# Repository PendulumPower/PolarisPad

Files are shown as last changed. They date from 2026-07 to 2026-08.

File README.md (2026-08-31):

# PolarisPad
A Macropad designed for space combat in games such as Star Citizen.<br>
Finished Device
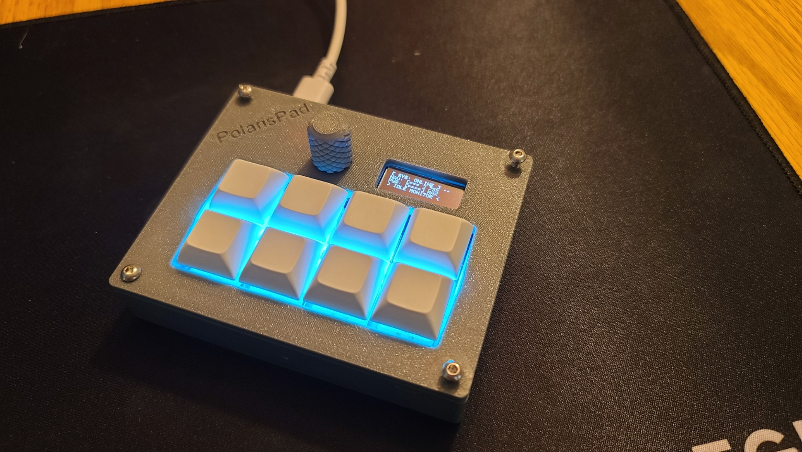
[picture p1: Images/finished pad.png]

Case:

Full Design:

PCB:

Schematic:

How to program:<br>
1. Connect the device to a computer using a usb-c data cable while pressing the boot button.<br>
2. Download the most recent .uf2 file from the releases.<br>
3. Drag and drop the .uf2 file into the folder for the device. It should close and reboot<br>
4. Done!<br>

BOM: <br>
-8 MX-Style switches <br>
-1 unsoldered Seeed XIAO RP2040 <br>
-8 through-hole 1N4148 Diodes <br>
-4 SK6812 MINI-E LEDs <br>
-1 EC11 Rotary encoders <br>
-1 0.91 inch OLED display

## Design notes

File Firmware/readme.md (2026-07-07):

# polarispad

polarispad

*A short description of the keyboard/project*

* Keyboard Maintainer: [Par Gunderson](https://github.com/PendulumPower)
* Hardware Supported: *The PCBs, controllers supported*
* Hardware Availability: *Links to where you can find this hardware*

Make example for this keyboard (after setting up your build environment):

    make polarispad:default

Flashing example for this keyboard:

    make polarispad:default:flash

See the [build environment setup](https://docs.qmk.fm/#/getting_started_build_tools) and the [make instructions](https://docs.qmk.fm/#/getting_started_make_guide) for more information. Brand new to QMK? Start with our [Complete Newbs Guide](https://docs.qmk.fm/#/newbs).

## Bootloader

Enter the bootloader in 3 ways:

* **Bootmagic reset**: Hold down the key at (0,0) in the matrix (usually the top left key or Escape) and plug in the keyboard
* **Physical reset button**: Briefly press the button on the back of the PCB - some may have pads you must short instead
* **Keycode in layout**: Press the key mapped to `QK_BOOT` if it is available

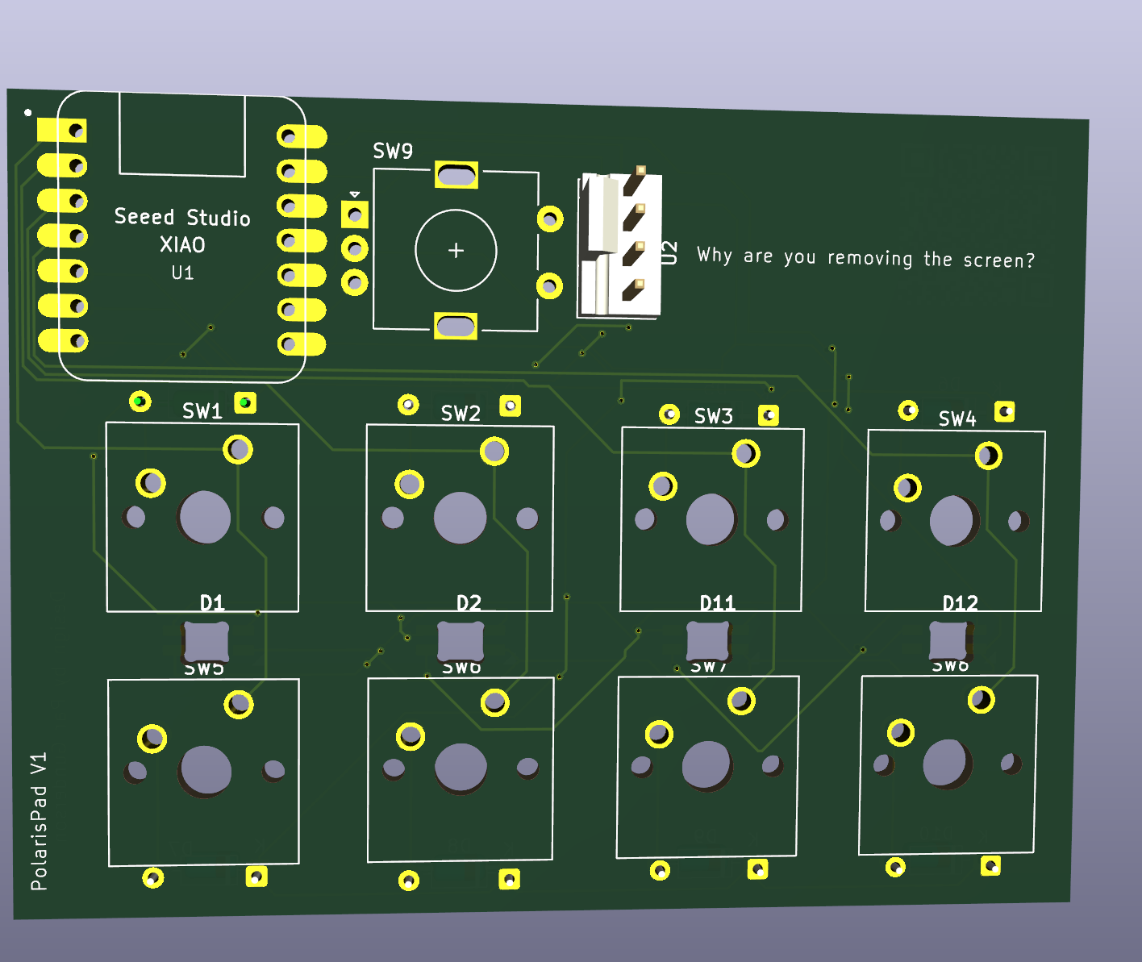
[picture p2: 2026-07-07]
Images/Screenshot 2026-07-06 182143.png

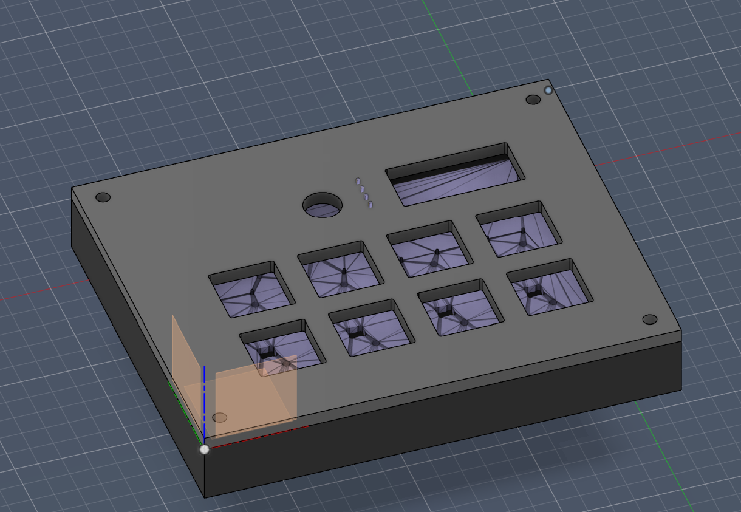
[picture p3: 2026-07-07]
Images/Screenshot 2026-07-06 095448.png

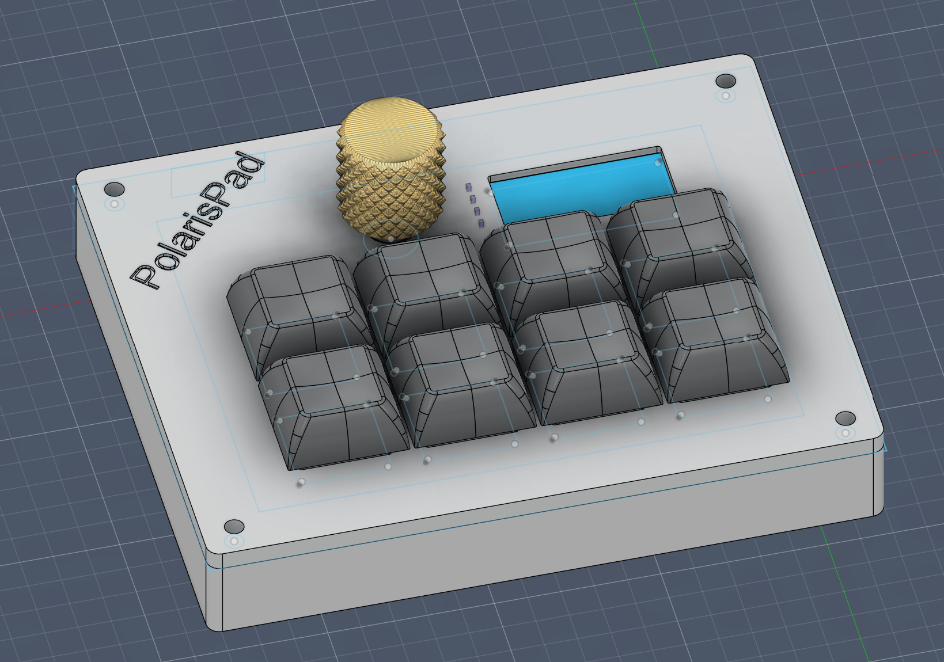
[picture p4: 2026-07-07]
Images/Screenshot 2026-07-06 175424.png

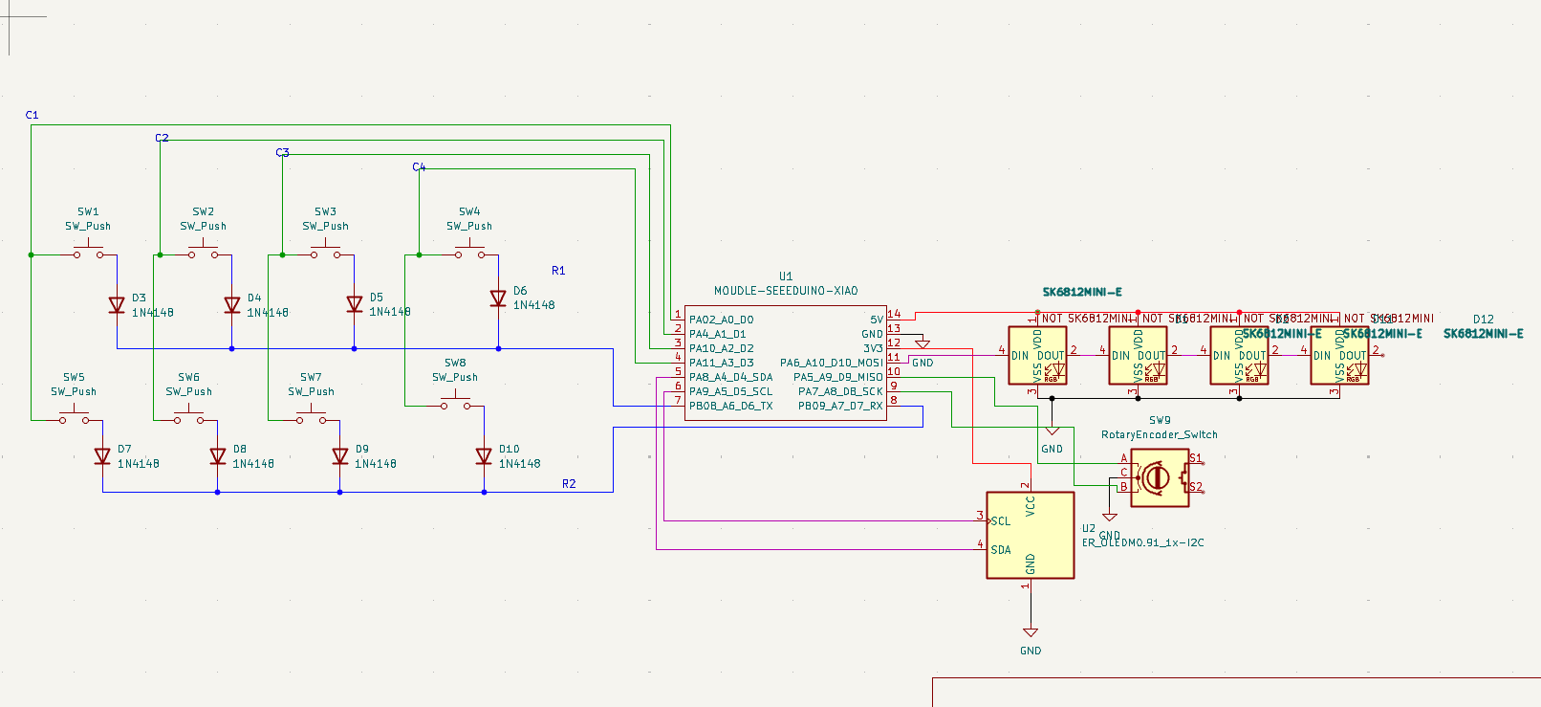
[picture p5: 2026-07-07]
Images/Screenshot 2026-07-07 163543.png

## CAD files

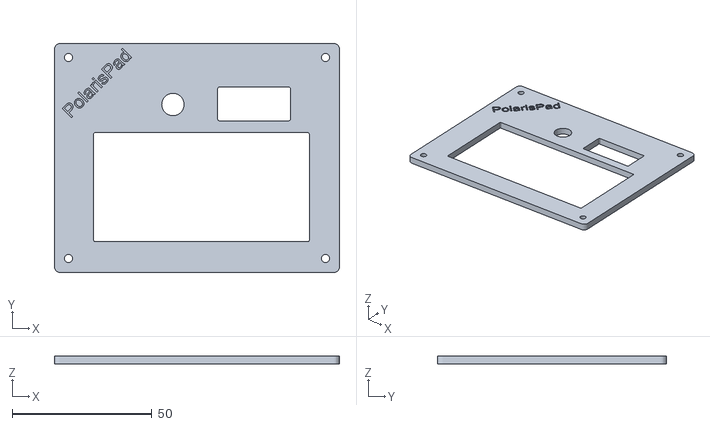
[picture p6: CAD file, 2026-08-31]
Production/PolarisPad_Case Top Plate.stl
101.8 x 81.8 x 3.00

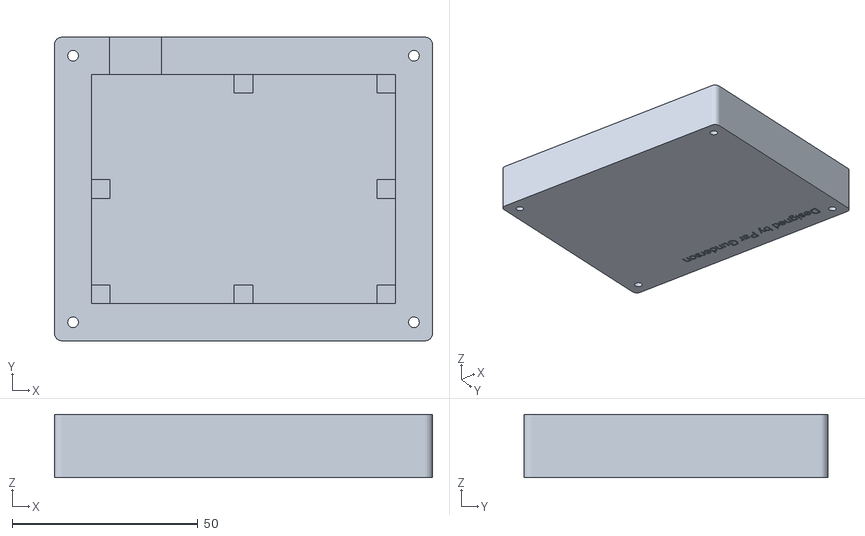
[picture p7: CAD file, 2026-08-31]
Production/PolarisPad_Case Bottom.stl
101.8 x 81.8 x 17.0

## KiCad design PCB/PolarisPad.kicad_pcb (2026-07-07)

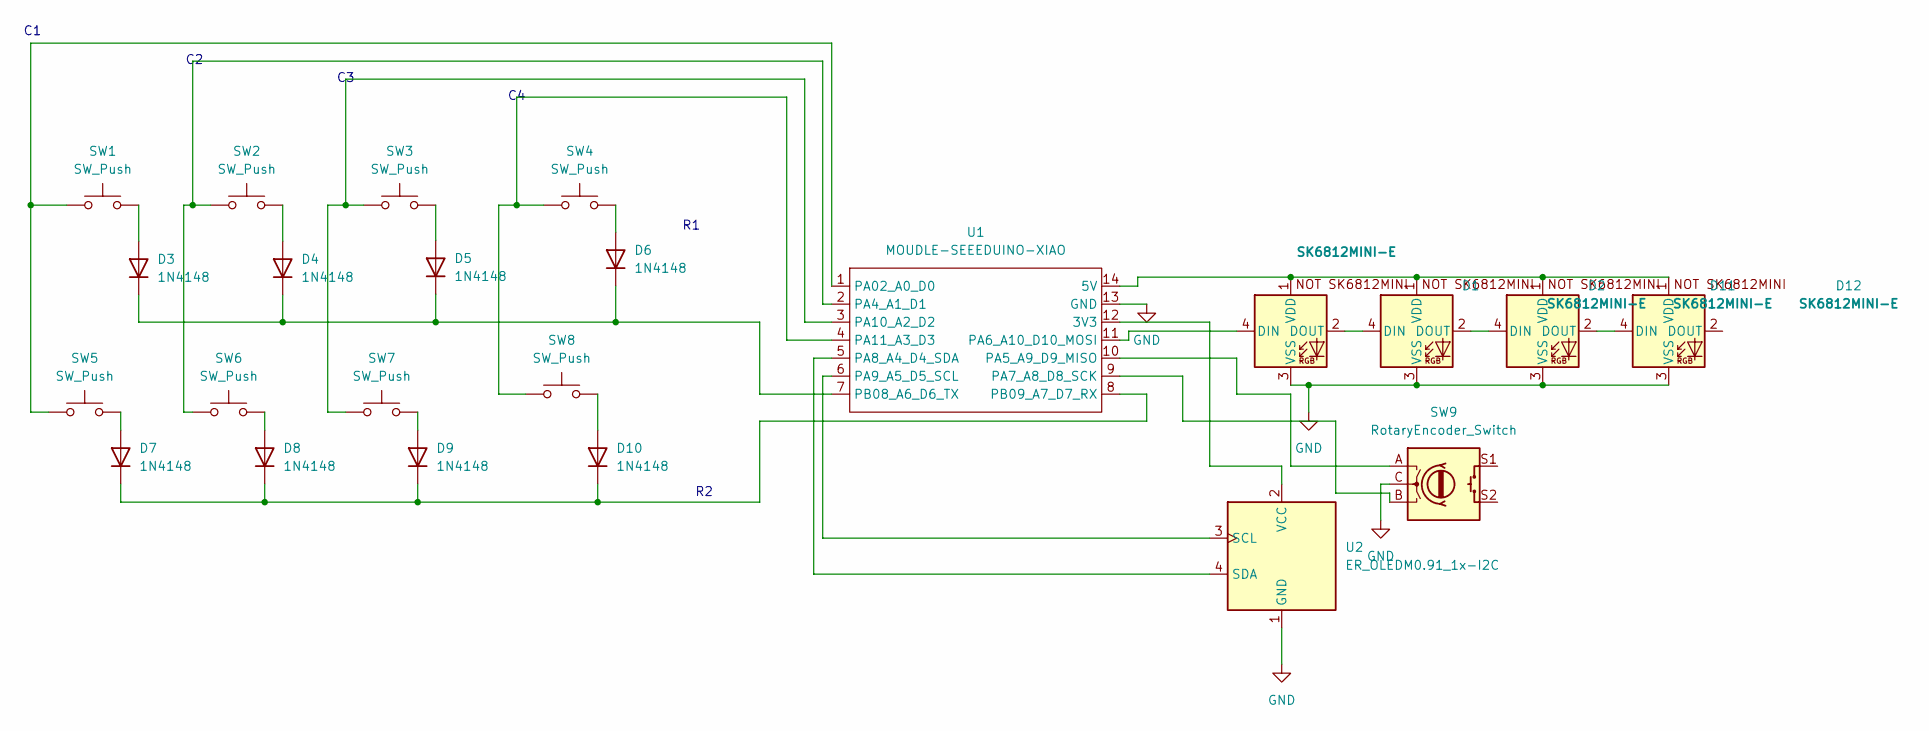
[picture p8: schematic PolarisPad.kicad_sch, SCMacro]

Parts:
D1, D2, D11, D12: SK6812MINI-E; SK6812MINI-E_fixed
D3, D4, D5, D6, D7, D8, D9, D10: 1N4148; D_DO-35_SOD27_P7.62mm_Horizontal
SW1, SW2, SW3, SW4, SW5, SW6, SW7, SW8: SW_Push; SW_Cherry_MX_1.00u_PCB
SW9: RotaryEncoder_Switch; RotaryEncoder_Alps_EC11E-Switch_Vertical_H20mm
U1: MOUDLE-SEEEDUINO-XIAO; XIAO-Generic-Hybrid-14P-2.54-21X17.8MM
U2: ER_OLEDM0.91_1x-I2C; FanPinHeader_1x04_P2.54mm_Vertical

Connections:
GND: D1.3 (VSS), D2.3 (VSS), D11.3 (VSS), D12.3 (VSS), SW9.C, U1.13 (GND), U2.1 (GND)
unnamed: D1.4 (DIN), U1.11 (PA6_A10_D10_MOSI)
unnamed: D1.2 (DOUT), D2.4 (DIN)
unnamed: D1.1 (VDD), D2.1 (VDD), D11.1 (VDD), D12.1 (VDD), U1.14 (5V)
unnamed: D3.2 (A), SW1.2
unnamed: D3.1 (K), D4.1 (K), D5.1 (K), D6.1 (K), U1.7 (PB08_A6_D6_TX)
unnamed: D4.2 (A), SW2.2
unnamed: D5.2 (A), SW3.2
unnamed: D6.2 (A), SW4.2
unnamed: D7.2 (A), SW5.2
unnamed: D8.2 (A), SW6.2
unnamed: D9.2 (A), SW7.2
unnamed: D10.2 (A), SW8.2
unnamed: D7.1 (K), D8.1 (K), D9.1 (K), D10.1 (K), U1.8 (PB09_A7_D7_RX)
unnamed: D2.2 (DOUT), D11.4 (DIN)
unnamed: D11.2 (DOUT), D12.4 (DIN)
unnamed: U1.12 (3V3), U2.2 (VCC)
unnamed: SW1.1, SW5.1, U1.1 (PA02_A0_D0)
unnamed: SW2.1, SW6.1, U1.2 (PA4_A1_D1)
unnamed: SW9.A, U1.10 (PA5_A9_D9_MISO)
unnamed: SW9.B, U1.9 (PA7_A8_D8_SCK)
unnamed: U1.5 (PA8_A4_D4_SDA), U2.4 (SDA)
unnamed: U1.6 (PA9_A5_D5_SCL), U2.3 (SCL)
unnamed: SW3.1, SW7.1, U1.3 (PA10_A2_D2)
unnamed: SW4.1, SW8.1, U1.4 (PA11_A3_D3)

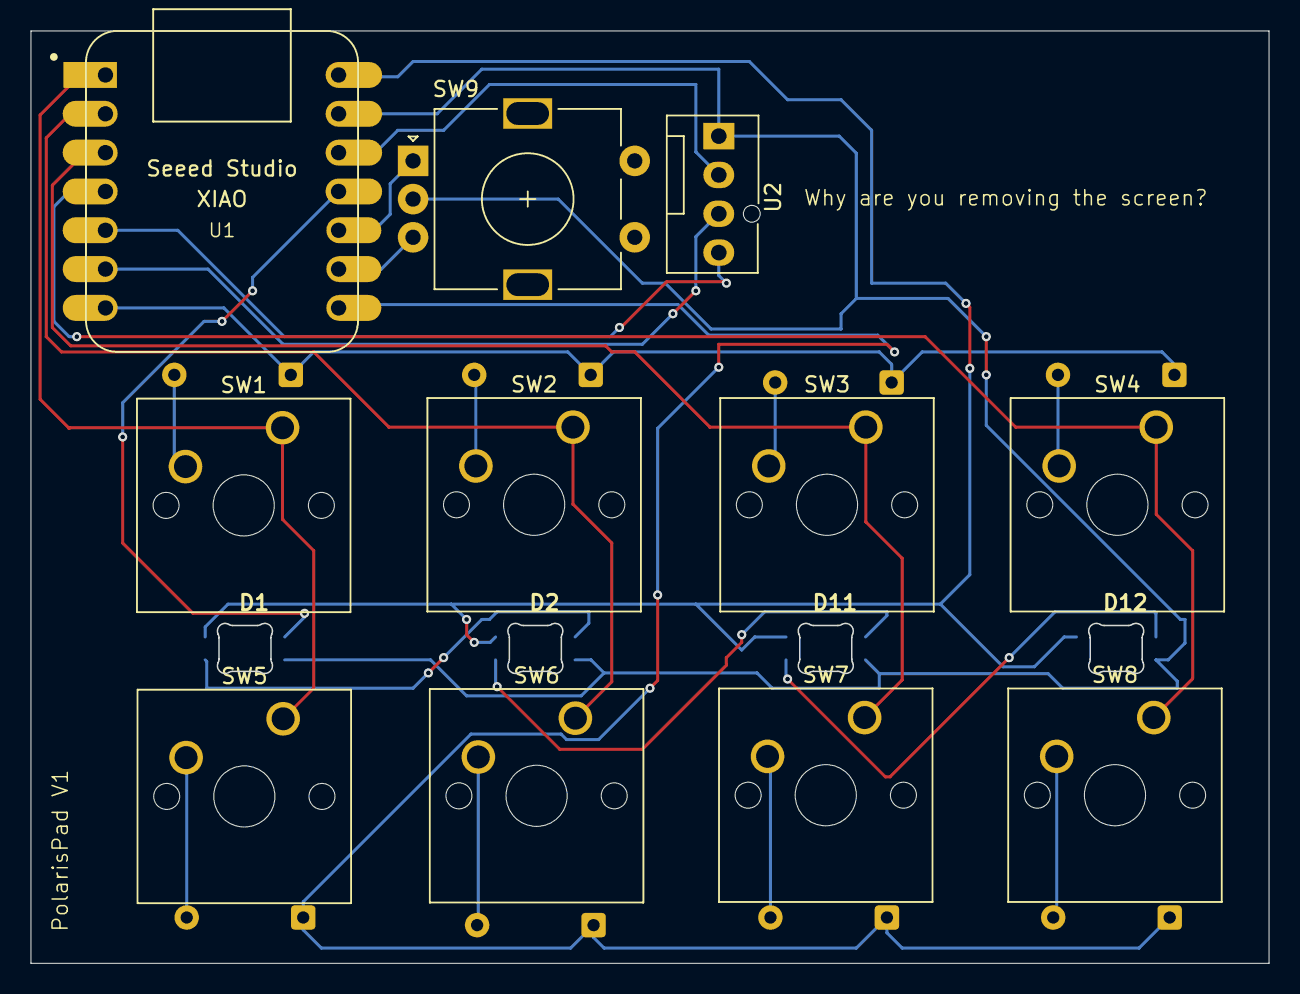
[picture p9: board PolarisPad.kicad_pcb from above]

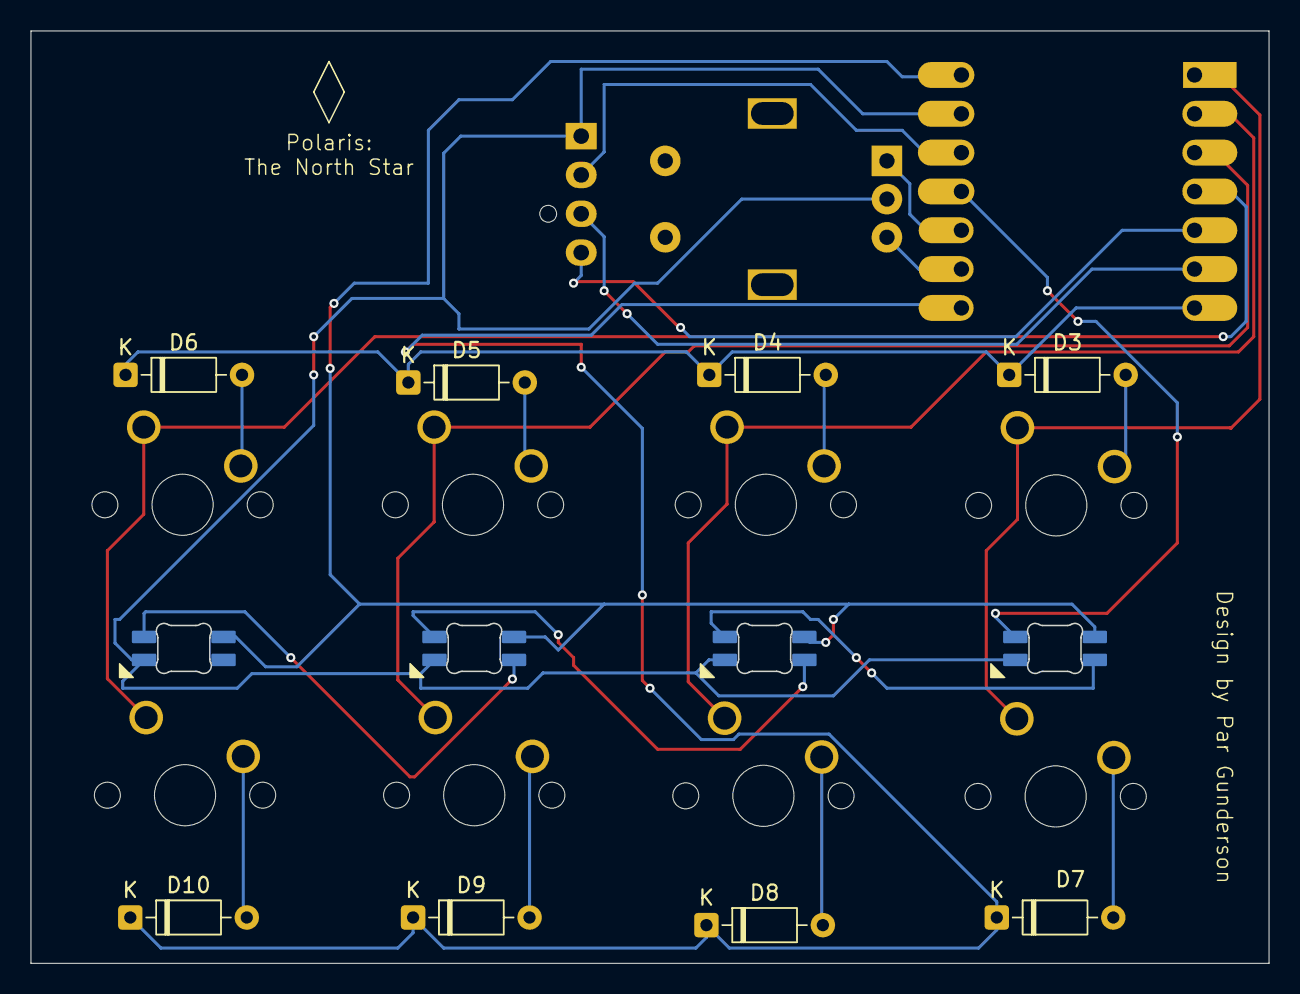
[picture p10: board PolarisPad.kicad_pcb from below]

Board: 2 copper layers, 81.0 x 61.0 mm, 23 parts (8 on the bottom side), 25 nets.

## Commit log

2026-07-07 Added all project and production files
    [Case Bottom.stl, Case Top Plate.stl, PolarisPad.kicad_pcb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]
2026-07-07 Add case design image to README
    Added an image link for case design in the README.
2026-07-07 Enhance README with design images and details
    Added images and descriptions for case design, full design, PCB, and schematic.
2026-07-07 Add BOM section to README
    Added Bill of Materials (BOM) section with components.
2026-08-31 Update README with programming instructions and BOM
    Added programming instructions and BOM details.
2026-08-31 Update README with finished device images
    Added images and details for the finished device and case.
